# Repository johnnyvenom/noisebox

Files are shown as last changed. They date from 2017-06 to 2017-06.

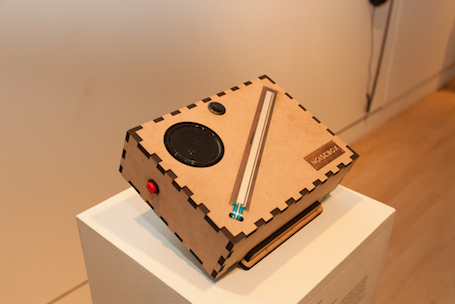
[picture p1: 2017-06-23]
Noisebox-2015-resources/images/noisebox1.jpg

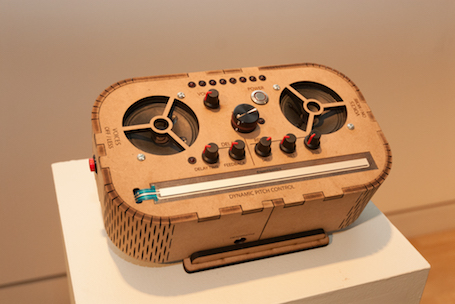
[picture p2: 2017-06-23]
Noisebox-2015-resources/images/noisebox2.jpg

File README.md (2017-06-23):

Noisebox rev3 - Fall 2016
=========================

## Setting up RPi: 

- Flashing new disk images: 
    - https://learn.adafruit.com/beaglebone-black-installing-operating-systems/
    - https://ccrma.stanford.edu/wiki/How_To_Get_Satellite_CCRMA
    - Won't flash holding down User Boot button? Use this: http://stackoverflow.com/questions/31725206/unable-to-flash-emmc-from-sd-card-beaglebone-black
- Check current OS: http://www.cyberciti.biz/faq/find-linux-distribution-name-version-number/
    - `cat /etc/*-release`
    - `lsb_release -a`
    - `uname -a`
    - `cat /proc/version
- Remote desktop for BBB: 
    - start vncserver `vncserver -geometry 1680x1050 -depth 24`
    - Mac: open screen share and put in IP address:5901
        + PW: tightvnc
    - info:
        + https://www.digitalocean.com/community/tutorials/how-to-set-up-vnc-server-on-debian-8
        + https://www.huement.com/web/beaglebone-screen-sharing-on-osx/
    - Advertise over Bonjour (not yet working): https://teachprimarycomputing.wordpress.com/2015/02/28/a-mac-geeks-guide-to-vnc-on-the-pi/
        + Netatalk for making shared device show up - check Ivan's distro. 
- Static IPs for multiple wireless networks (new procedure on Debian Jessie)
    + https://www.raspberrypi.org/forums/viewtopic.php?f=91&t=132553
- Power switch:
    + http://www.raspberry-pi-geek.com/Archive/2013/01/Adding-an-On-Off-switch-to-your-Raspberry-Pi
    + http://www.instructables.com/id/Simple-Raspberry-Pi-Shutdown-Button/
    + Long press shut down button: https://www.raspberrypi.org/forums/viewtopic.php?f=32&t=133111
    + 

## Ingredients list for a Satellite CCRMA (or similar) Noisebox: 

- Raspberry Pi ($52) rs - http://www.robotshop.com/ca/en/raspberry-pi-3-computer-board.html
- Arduino Nano ($13) rs - http://www.robotshop.com/ca/en/pro-mini-arduino-microcontroller.html
    + teensy
- Battery ($20) - ada - https://www.adafruit.com/products/1959
    + 2.4A
- Power Supply switch ($30) rs - http://www.robotshop.com/ca/en/on-off-power-supply-switch-raspberry-pi.html
- 3 x USB cable ($9)
- microSD card ($10)
- Buttons and switches ($5)
- Sensor: Linear FSR ($10?)
- IMU ($20)
- Speaker ($4)
- Amplifier ($5)
- USB audio I/O ($5)
- Breadboard ($5)
- Housing ($10)
- Hardware and jacks ($10)
- TOTAL: $208

### Static IP setup

Write down the following information. . .

- inet addr – 192.168.1.114 (Pi's Current IP Address)
- Bcast –  192.168.1.255 (The Broadcast IP Range)
- Mask –  255.255.255.0 (Subnet Mask Address)
- Gateway - 192.168.1.1
- Destination - 192.168.1.0

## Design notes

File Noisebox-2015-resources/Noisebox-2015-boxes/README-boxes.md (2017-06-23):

Noisebox Enclosures
===================

25 July - Saturday:

Revisions to make:
1. Reduce overall dimensions to 11 x 2.5 x 6.5. Yes? 
2. Reduce walls by 1mm on each flat side to fit better. 
3. Etch out recesses for potentiometers to set in. 
4. Remove pot guide holes - drill separately after. 
5. Add text - Pitch control; voices; 
6. Add arrows to voices LEDS
7. LEDS for voices and delay indicator
8. Recess for headphone

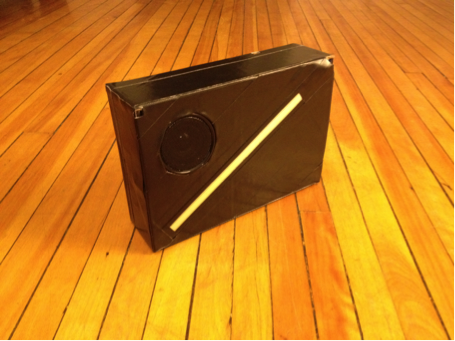
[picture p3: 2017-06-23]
Noisebox-2015-resources/images/noisebox0.png

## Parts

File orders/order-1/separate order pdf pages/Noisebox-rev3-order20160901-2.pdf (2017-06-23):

Noisebox rev3 materials list
2016-08-01 John Sullivan - IDMIL
Item # | Description | Vendor Item ID Cost/Unit Quant Cost/Instr. | Notes | Use
Processing 1 2 3 4 5 6 | Raspberry Pi 3 Teensy 3.2 Battery 5V 2.4A Sensor I/O cape WiFi dongle microSD card 8gb | RobotShop RB-Ras-12 CAD 51.99 1 CAD 51.99 RobotShop RB-Pjr-04 CAD 25.38 1 CAD 25.38 Abra BAT-PB-01 CAD 39.94 1 CAD 39.94 in house Ivan 1 Abra PI-WIFI-M CAD 10.57 1 Abra BBB-8GB-10 CAD 13.93 1 CAD 13.93 | Have at least 4 at IDMIL… enough to start | Core processor Sensor processing and filtering Wireless power supply Sensor I/O Wireless communication RPi storage

Sensors and controls

Sound output

Hardware, cables, accessories

7 | Buttons - mom (power) | Abra | PBS-33MM-BLCAD 2.09 | 1 | CAD 2.09 | RPi soft shutdown
8 | LED - Power (Blue) | Abra | LED-5B | CAD 1.11 | 1 | CAD 1.11 | | Power indicator (optional)
9 | Switch - Power | Abra | COM-11155 CAD 2.10 | 1 | CAD 2.10 | Power supply switch (after soft shutdown)
10 | Buttons (voice on - grn) | RobotShop RB-Spa-674 CAD 2.50 | 1 | CAD 2.50 | Voice(s) on
11 | Buttons (voice off - red) | RobotShop RB-Spa-324 CAD 2.50 | 1 | CAD 2.50 | Voice(s) off
12 | Linear SoftPot - 200mm | Digikey | 905-1051-ND CAD 16.66 | 1 | CAD 16.66 | Dynamic pitch control
13 | Analog accelerometer | RobotShop RB-Ite-11 | CAD 3.77 | 1 | CAD 3.77 | Motion acquisition
14 | Knob (volume) | Digikey | PDB182-E420K-103A-ND CAD 2.70 | 1 | 50K 2 gang (not in stock). Check part #. | Volume knob
15 | USB sound card | Abra | 1475-ADA | CAD 6.93 | 1 | CAD 6.93 | | Audio I/O
| OPTION 1
16 | Stereo Class-D amp | RobotShop RB-Dfr-419 CAD 7.56 | 1 | CAD 7.56 | Audio amplifier
17 | Speaker 4Ω 3W | Abra | 1314-ADA | CAD 2.73 | 2 | CAD 5.46 | | Audio output
18 | 3.5mm TRS male | Abra | 867-ADA | CAD 4.13 | 1 | CAD 4.13 | | Audio cable - sound card to amp
| OPTION 2
19 | USB powered speakers | Abra | 1363-ADA | CAD 13.93 | 1 | | | Alternative to Option 1 but not as good
20 | Acrylic housing | in house | Ivan | | 1 | | | Instrument body
21 | USB cable panel mount | Abra | 937-ADA | CAD 5.53 | 1 | CAD 5.53 | | Panel mount battery charging port
22 | Ethernet cable panel mount | Abra | 909-ADA | CAD 6.85 | 1 | CAD 6.85 | | Panel mount ethernet port
23 | Protoboard (3pk) | Abra | 571-ADA | CAD 5.83 | 1 | CAD 5.83 | misc bulk hardware; 3pack for 17.95 | Wiring hub
24 | headers male 1x40 (10pk) | RobotShop RB-Cyt-53 | CAD 0.23 | 3 | CAD 0.69 | misc bulk hardware; 10 pack = $2.31 | Wiring connections
25 | headers female 1x40 (1pk) | RobotShop RB-Cyt-58 | CAD 0.44 | 1 | CAD 0.44 | misc bulk hardware | Wiring connections - Teensy
26 | headers female 2x20 (1pk) | Abra | 1037-POLOLUCAD 1.75 | 1 | CAD 1.75 | misc bulk hardware | RPi to cape connector
27 | Button quick connect wires (5pk) | Abra | 1152-ADA | CAD 1.39 | 1 | | misc bulk hardware; 5 pack = $6.93 | Button wiring connectors
28 | JST connectors | Abra | PRT-09749 CAD 1.53 | 4 | misc bulk hardware | Button wire to protoboard
29 | 2.5mm standoffs (4pack set) | Abra | 1952P | CAD 1.95 | 1 | | misc bulk hardware | Mounting hardware
30 | M2.5 spacers (25pk) | Abra | 1975P | CAD 0.08 | 4 | CAD 0.33 | misc bulk hardware; 25 pack = $2.09 | Mounting hardware
31 | M2.5 Machine hex nut (25pk) | Abra | 1967P | CAD 0.06 | 4 | CAD 0.22 | misc bulk hardware; 25 pack = $1.39 | Mounting hardware
32 | M2.5 Machine screw (25pk) | Abra | 1968P | CAD 0.06 | 4 | CAD 0.22 | misc bulk hardware; 25 pack = $1.39 | Mounting hardware
33 | LED holder | Abra | LMH-1 | CAD 0.15 | 1 | | misc bulk hardware | Mounting hardware
TOTAL INSTRUMENT COST: CAD 207.93

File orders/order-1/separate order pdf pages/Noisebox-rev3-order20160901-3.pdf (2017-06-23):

Noisebox rev3 materials list | Vendor comparison
John Sullivan | Color key: 1st choice
USD 1.00 = CAD 1.31 | 1st choice
# | Description

Quantity
per inst. | DigiKey | Cost per unit

Cost per
instrument RobotShop

Cost per
unit

Cost per
instrument Abra

Cost per
unit

Cost per
instrument | Adafruit | Cost (USD) | Cost (CAD) | Other | Item | Cost

Quantity in
lab | Notes | Use
Processing
1 | Raspberry Pi 3 | 1 | 1690-1000-ND CAD | 67.54 | RB-Ras-12 | CAD 51.99 CAD 51.99 | RASPBERRY PI 3CAD 62.71 | 3055 | USD 39.95 | CAD 52.32 | 0 | Core processor
2 | Teensy 3.2 | 1 | 1568-1231-ND CAD | 31.99 | RB-Pjr-04 | CAD 25.38 CAD 25.38 | TEENSY-3.2 CAD 29.33 | 2756 | USD 19.95 | CAD 26.13 | 2 | Adafruit out of stock | Sensor processing and filtering
3 | Battery 5V 2.4A | 1 | n/a | n/a | BAT-PB-01 CAD 39.94 CAD 39.94 | n/a | Amazon.ca RAVPower 6700mAh CAD 20.79 | 4 | Have at least 4 at IDMIL… enough to start | Wireless power supply
4 | Sensor I/O cape | 1 | n/a | n/a | n/a | n/a | Pi Muxi Control Ivan | Ivan | Sensor I/O
5 | WiFi dongle | 1 | 1528-1439-ND CAD | 16.99 | RB-Ada-67 CAD 15.32 | PI-WIFI-M | CAD 10.57 CAD 10.57 | 814 | USD 11.95 | CAD 15.65 | 4 | Wireless communication
6 | microSD card 8gb | 1 | P17033-ND | CAD | 14.72 | BBB-8GB-10 CAD 13.93 CAD 13.93 | 1294 | USD 9.95 | CAD 13.03 | 1 | RPi storage
Sensors and controls
7 | Buttons - mom (power) | 1 | EG1900-ND | CAD | 2.73 | PBS-33MM-BLCAD 2.09 CAD | 2.09 | 0 | DigiKey unit cost: 2.73 | RPi soft shutdown
8 | LED - Power (Blue) | 1 | LED-5B | CAD 1.11 CAD | 1.11 | Power indicator (optional)
9 | Switch - Power | 1 | COM-11155 CAD 2.10 CAD | 2.10 | 481 | USD 4.95 | CAD 6.48 | Power supply switch (after soft shutdown)
10 | Buttons (voice on - grn) | 1 | EG1930-ND | CAD | 5.46 | RB-Spa-674 CAD 2.50 CAD | 2.50 | COM-90341 CAD 2.73 | 1504 | USD 0.95 | CAD 1.24 | 0 | Also black and yellow from Adafruit | Voice(s) on
11 | Buttons (voice off - red) | 1 | EG1930-ND | CAD | 5.46 | RB-Spa-324 CAD 2.50 CAD | 2.50 | COM-09336 CAD 2.73 | 1445 | USD 0.95 | CAD 1.24 | 0 | Voice(s) off
12 | Linear SoftPot - 200mm | 1 | 905-1051-ND CAD | 16.66 CAD 16.66 | SEN-08679 CAD 30.73 | 0 | Dynamic pitch control
13 | Analog accelerometer | 1 | 1568-1044-ND CAD | 21.13 | RB-Ite-11 | CAD 3.77 CAD | 3.77 | SENS-33 | CAD 11.19 | 163 | USD 14.95 | CAD 19.58 | 0 | Motion acquisition
14 | Knob (volume) | 1 | PDB182-E420K-103A-ND CAD | 2.70 CAD 2.70 | 4 | 50K double stack / not currently in stock… check part #. | Volume knob
Sound output
15 | USB sound card | 1 | 1475-ADA | CAD 6.93 CAD | 6.93 | 1475 | USD 4.95 | CAD 6.48 | 4 | Audio I/O
OPTION 1
16 | Stereo Class-D amp | 1 | 1528-1380-ND CAD | 12.65 | RB-Dfr-419 CAD 7.56 CAD | 7.56 | 1552-ADA | CAD 13.93 | 987 | USD 8.95 | CAD 11.72 | 2 | Ref: https://goo.gl/4Ec353 | Audio amplifier
17 | Speaker 4Ω 3W | 2 | n/a | 1314-ADA | CAD 2.73 CAD | 5.46 | 1314 | USD 3.90 | CAD 5.11 | Addison | 3 | Unit cost: USD 1.95 | Audio output
18 | 3.5mm TRS male | 1 | 867-ADA | CAD 4.13 CAD | 4.13 | 876 | USD 2.95 | CAD 3.86 | Addison | 0 | Audio cable - sound card to amp
OPTION 2
19 | USB powered speakers | 1 | 1363-ADA | CAD 13.93 | 1363 | USD 9.95 | CAD 13.03 | 0 | Sound output
Hardware, cables, accessories
20 | Acrylic housing | 1 | Ivan | Ivan | Instrument body
21 | USB cable panel mount | 1 | SC1837-ND | CAD | 17.61 | 937-ADA | CAD 5.53 CAD | 5.53 | 937 | USD 3.95 | CAD 5.17 | 0 | Panel mount battery charging port
22 | Ethernet cable panel mount | 1 | EHRJ45P6S-ND CAD | 14.67 | 909-ADA | CAD 6.85 CAD | 6.85 | 909 | USD 4.95 | CAD 6.48 | 0 | Panel mount ethernet port
23 | Protoboard (3pk) | 1 | 571-ADA | CAD 5.83 CAD | 5.83 | 571 | USD 12.50 | CAD 16.37 | 2/0 | *3 pack from Abra 17.50 | Wiring hub
24 | headers male 1x40 (10pk) | 3 | RB-Cyt-53 | CAD 2.31 CAD | 0.69 | SH-2 | CAD 2.91 | 0 | RS = 10 pack; Abra unit price = .97 | Wiring connections
25 | headers female 1x40 (1pk) | 1 | RB-Cyt-58 | CAD 0.44 CAD | 0.44 | FH-1 | CAD 0.97 | 0 | 1-pack: order multiples | Wiring connections - Teensy
26 | headers female 2x20 (1pk) | 1 | RB-Ada-27 CAD 3.78 | 1037-POLOLUCAD 1.75 CAD | 1.75 | 0 | RobotShop = 5 pack; Abra = 2x20 block | RPi to cape connector
27 | Button quick connect wires (5pk) | 1 | 1152-Ada | CAD 6.93 CAD | 6.93 | 1152 | USD 4.95 | CAD 6.48 | Button wiring connectors
28 | JST connectors | 4 | 455-2247-ND CAD 2.9 | PRT-09749 CAD 1.53 CAD | 6.12 | Unit price (Abra): $1.53 | Button wire to protoboard
29 | 2.5mm standoffs (4pack set) | 1 | 1952P | CAD 1.95 CAD | 1.95 | 2336 | USD 1.50 | CAD 1.96 | optional | ***MUST BE 2.5M not 3M | Mounting hardware
30 | M2.5 spacers (25pk) | 4 | 1975P | CAD 2.09 | multipack | Mounting hardware
31 | M2.5 Machine hex nut (25pk) | 4 | 1967P | CAD 1.39 | multipack | Mounting hardware
32 | M2.5 Machine screw (25pk) | 4 | 1968P | CAD 1.39 | multipack | Mounting hardware
33 | LED holder | 1 | LMH-1 | CAD 0.15 CAD | 0.15 | multipack | Mounting hardware
* Should get M2.5 screws 20mm

2016-08-01

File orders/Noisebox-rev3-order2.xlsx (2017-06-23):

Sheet: Order Form
FOAPAL: |  | PROJECT: John Sullivan - Noisebox rev3 (comprehensive exams)
Quantity | Description | Part number/Supplier ID | URL | Price | (All prices are CAD) |  | Ordered Date
ABRA ELECTRONICS
1 | Pololu Female crimp pins | 1930-POLOLU | https://abra-electronics.com/connectors/connector-housing/1930-pololu-female-crimp-pins-for-01-housings-100-pack-1930-pololu.html | $8.33 |  | $8.33
1 | Polulu male crimp pins | 1931-POLOLU | https://abra-electronics.com/connectors/connector-housing/1931-pololu-male-crimp-pins-for-01-housings-100-pack-1931-pololu.html | $11.13 |  | $11.13
8 | Buttons - 33m | PBS-33MM-BL | https://abra-electronics.com/electromechanical/switches/pushbutton-switches/pbs-33mm-bl-push-button-33mm-blue-pbs-33mm-bl.html | $2.09 |  | $8.34
1 | F/F 6" jumper wires | 266-ADA | https://abra-electronics.com/wirecable/jumper-wire-assembly/266-premium-female-female-jumper-wires-40-x-6-266-ada.html | $8.33 |  | $8.33
1 | F/F 3" jumper wires | 794-ADA | https://abra-electronics.com/wirecable/jumper-wire-assembly/794-premium-female-female-jumper-wires-40-x-3-75mm-794-ada.html | $8.33 |  | $8.33
1 | M/M 3" jumper wires | 759-ADA | https://abra-electronics.com/robotics-embedded-electronics/cables-wires/759-premium-male-male-jumper-wires-40-x-3-75mm-759-ada.html | $8.33 |  | $8.33
1 | F/M 3" jumper wires | 825-ADA | https://abra-electronics.com/robotics-embedded-electronics/cables-wires/825-premium-female-male-extension-jumper-wires-40-x-3-75mm-825-ada.html | $8.33 |  | $8.33
1 | F/M 6" jumper wires | 826-ADA | https://abra-electronics.com/robotics-embedded-electronics/cables-wires/826-premium-female-male-extension-jumper-wires-40-x-6-150mm-826-ada.html | $8.33 |  | $8.33
1 | M/M 6" jumper wires | 758-ADA | https://abra-electronics.com/robotics-embedded-electronics/cables-wires/758-premium-male-male-jumper-wires-40-x-6-150mm-758-ada.html | $8.33 |  | $8.33
2 | Perf board w solder pads | BRD-ARD-1 | https://abra-electronics.com/boards/printed-circuit-boards/brd-ard-1-pcb-81cm-x-63cm-brd-ard-1.html | $4.89 |  | $9.77
1 | Perf board bare | 22-518 | https://abra-electronics.com/boards/prepunched-boards/22-518-3-3-4-x-8-perforated-bare-phenolic-prototype-board.html | $9.94 |  | $9.94
4 | Button - power/momentary | 3105-ADA | https://abra-electronics.com/electromechanical/switches/pushbutton-switches/3105-ada-mini-illuminated-momentary-pushbutton-blue-power-symbol.html | $2.73 |  | $10.92
2 | Button - 16mm - grn | PBS-A-110 | https://abra-electronics.com/switches/pushbutton-switches/pbs-a-110-16mm-panel-mount-momentary-pushbutton-green-pbs-a-110.html | $1.81 |  | $3.61
2 | Button - 16mm - black | PBS-A-105 | https://abra-electronics.com/switches/pushbutton-switches/pbs-a-105-16mm-panel-mount-momentary-pushbutton-black-pbs-a-105.html | $1.67 |  | $3.33
2 | Button - 16mm - red | PBS-A-100 | https://abra-electronics.com/switches/pushbutton-switches/pbs-a-100-16mm-panel-mount-momentary-pushbutton-red-pbs-a-100.html | $1.67 |  | $3.33
4 | USB power supply cable w/ switch | PI2-SWITCH | https://abra-electronics.com/robotics-embedded-electronics/raspberry-pi-en-3/cables-connectors/pi2-switch-micro-usb-cable-w-switch.html | $7.49 |  | $29.96
 |  |  |  |  | SUBTOTAL | $135.70
 |  |  |  |  | Shipping | $13.99
 |  |  |  |  | Taxes | $22.43
 |  |  |  |  | Total: | $172.12
Order details and totals
 |  |  |  |  | Total for order: | $172.12

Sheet: Instrument - parts list
Noisebox rev3 materials list
2016-08-01 | John Sullivan - IDMIL
Item # | Description | Vendor | Item ID | Cost/Unit | Quant | Cost/Instr. | Notes | Use
Processing
1 | Raspberry Pi 3 | RobotShop | RB-Ras-12 (http://www.robotshop.com/ca/en/raspberry-pi-3-computer-board.html) | CAD 51.99 | 1 | CAD 51.99 |  | Core processor
2 | Teensy 3.2 | RobotShop | RB-Pjr-04 (http://www.robotshop.com/ca/en/teensy-32-usb-microcontroller-development-board.html) | CAD 25.38 | 1 | CAD 25.38 |  | Sensor processing and filtering
3 | Battery 5V 2.4A | Abra | BAT-PB-01 (https://abra-electronics.com/batteries-holders/battery-packs-rechargeable/bat-pb-01-8000-mah-rapid-charge-power-bank-with-14-integrated-leds-for-iphone-samsun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) | CAD 39.94 | 1 | CAD 39.94 | Have at least 4 at IDMIL… enough to start | Wireless power supply
4 | Sensor I/O cape | in house | Ivan |  | 1 |  |  | Sensor I/O
5 | WiFi dongle | Abra | PI-WIFI-M (https://abra-electronics.com/robotics-embedded-electronics/beagle-bone/pi-wifi-m-usb-wireless-miniature-module-pi-wifi-m.html) | CAD 10.57 | 1 |  |  | Wireless communication
6 | microSD card 8gb | Abra | BBB-8GB-10 (https://abra-electronics.com/robotics-embedded-electronics/beagle-bone/bbb-8gb-4-micro-sdhc-memory-card-8gb-class-4-bbb-8gb-4.html) | CAD 13.93 | 1 | CAD 13.93 |  | RPi storage
Sensors and controls
7 | Buttons - mom (power) | Abra | PBS-33MM-BL (https://abra-electronics.com/robotics-embedded-electronics/sparkfun/components/buttons-switches/pbs-33mm-bl-push-button-33mm-blue-pbs-33mm-bl.html) | CAD 2.09 | 1 | CAD 2.09 |  | RPi soft shutdown
8 | LED - Power (Blue) | Abra | LED-5B (https://abra-electronics.com/opto-illumination/leds-bare/5mmt13-4-leds/led-5b-5mm-blue-led-led-5b.html) | CAD 1.11 | 1 | CAD 1.11 |  | Power indicator (optional)
9 | Switch - Power | Abra | COM-11155 (https://abra-electronics.com/robotics-embedded-electronics/sparkfun/components/buttons-switches/com-11155-rocker-switch-round-w-blue-led-com-11155.html) | CAD 2.10 | 1 | CAD 2.10 |  | Power supply switch (after soft shutdown)
10 | Buttons (voice on - grn) | RobotShop | RB-Spa-674 (http://www.robotshop.com/ca/en/concave-button-red.html) | CAD 2.50 | 1 | CAD 2.50 |  | Voice(s) on
11 | Buttons (voice off - red) | RobotShop | RB-Spa-324 (http://www.robotshop.com/ca/en/sfe-concave-button-green.html) | CAD 2.50 | 1 | CAD 2.50 |  | Voice(s) off
12 | Linear SoftPot - 200mm | Digikey | 905-1051-ND (http://www.digikey.ca/product-search/en?keywords=905-1051-ND) | CAD 16.66 | 1 | CAD 16.66 |  | Dynamic pitch control
13 | Analog accelerometer | RobotShop | RB-Ite-11 (http://www.robotshop.com/ca/en/3-axis-accelerometer-module.html) | CAD 3.77 | 1 | CAD 3.77 |  | Motion acquisition
14 | Knob (volume) | Digikey | PDB182-E420K-103A-ND (https://www.digikey.ca/product-detail/en/bourns-inc/PDB182-E420K-103A/PDB182-E420K-103A-ND/3780709) | CAD 2.70 | 1 |  | 50K 2 gang (not in stock). Check part #. | Volume knob
Sound output
15 | USB sound card | Abra | 1475-ADA (https://abra-electronics.com/computer-accessories/usb-adapters-cables-hubs-other/1475-ada-usb-audio-adapter-works-with-raspberry-pi-1475-ada.html) | CAD 6.93 | 1 | CAD 6.93 |  | Audio I/O
 | OPTION 1
16 | Stereo Class-D amp | RobotShop | RB-Dfr-419 (http://www.robotshop.com/ca/en/3w-audio-stereo-amplifier.html) | CAD 7.56 | 1 | CAD 7.56 |  | Audio amplifier
17 | Speaker 4Ω 3W | Abra | 1314-ADA (https://abra-electronics.com/audible-devices/speakers/1314-ada-speaker-3-diameter-4-ohm-3-watt-1314-ada.html) | CAD 2.73 | 2 | CAD 5.46 |  | Audio output
18 | 3.5mm TRS male | Abra | 867-ADA (https://abra-electronics.com/robotics-embedded-electronics/adafruit/wires-cables/876-ada-stereo-35mm-plug-plug-audio-cable-6-feet-876-ada.html) | CAD 4.13 | 1 | CAD 4.13 |  | Audio cable - sound card to amp
 | OPTION 2
19 | USB powered speakers | Abra | 1363-ADA (https://abra-electronics.com/audible-devices/speakers/1363-ada-usb-powered-speakers-1363-ada.html) | CAD 13.93 | 1 |  |  | Alternative to Option 1 but not as good
Hardware, cables, accessories
20 | Acrylic housing | in house | Ivan |  | 1 |  |  | Instrument body
21 | USB cable panel mount | Abra | 937-ADA (https://abra-electronics.com/robotics-embedded-electronics/adafruit/raspberry-pi-en-2/cables/937-panel-mount-usb-cable-b-female-to-micro-b-male-937-ada.html) | CAD 5.53 | 1 | CAD 5.53 |  | Panel mount battery charging port
22 | Ethernet cable panel mount | Abra | 909-ADA (https://abra-electronics.com/robotics-embedded-electronics/adafruit/raspberry-pi-en-2/cables/909-panel-mount-ethernet-extension-cable-909-ada.html) | CAD 6.85 | 1 | CAD 6.85 |  | Panel mount ethernet port
23 | Protoboard (3pk) | Abra | 571-ADA (https://abra-electronics.com/boards/printed-circuit-boards/571-ada-adafruit-perma-proto-half-sized-breadboard-pcb-3-pack.html) | CAD 5.83 | 1 | CAD 5.83 | misc bulk hardware; 3pack for 17.95 | Wiring hub
24 | headers male 1x40 (10pk) | RobotShop | RB-Cyt-53 (http://www.robotshop.com/ca/en/break-away-headers-straight.html) | CAD 0.23 | 3 | CAD 0.69 | misc bulk hardware; 10 pack = $2.31 | Wiring connections
25 | headers female 1x40 (1pk) | RobotShop | RB-Cyt-58 (http://www.robotshop.com/ca/en/straight-female-headers.html) | CAD 0.44 | 1 | CAD 0.44 | misc bulk hardware | Wiring connections - Teensy
26 | headers female 2x20 (1pk) | Abra | 1037-POLOLU (https://abra-electronics.com/connectors/headers/female/1037-pololu-0.100-2.54-mm-female-header-2x20-pin-straight.html) | CAD 1.75 | 1 | CAD 1.75 | misc bulk hardware | RPi to cape connector
27 | Button quick connect wires (5pk) | Abra | 1152-ADA (https://abra-electronics.com/robotics-embedded-electronics/adafruit/components-parts/buttons/1152-ada-arcade-button-quick-connect-wire-pair-set-of-10-pairs-11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) | CAD 1.39 | 1 |  | misc bulk hardware; 5 pack = $6.93 | Button wiring connectors
28 | JST connectors | Abra | PRT-09749 (https://abra-electronics.com/connectors/jst-connectors/prt-09749-jst-right-angle-connector-through-hole-2-pin-prt-09749.html) | CAD 1.53 | 4 |  | misc bulk hardware | Button wire to protoboard
29 | 2.5mm standoffs (4pack set) | Abra | 1952P (https://abra-electronics.com/hardware/standoffs/standoffs-aluminum-m-f/1952p-aluminum-standoff-for-raspberry-pi-11mm-length-m2.5-thread-m-f-4-pack.html) | CAD 1.95 | 1 |  | misc bulk hardware | Mounting hardware
30 | M2.5 spacers (25pk) | Abra | 1975P (https://abra-electronics.com/hardware/spacers/1975p-nylon-spacer-12mm-length-4mm-od-2.7mm-id-25-pack.html) | CAD 0.08 | 4 | CAD 0.33 | misc bulk hardware; 25 pack = $2.09 | Mounting hardware
31 | M2.5 Machine hex nut (25pk) | Abra | 1967P (https://abra-electronics.com/hardware/metric-hardware-nickel-plated-nuts/1967p-machine-hex-nut-m2.5-25-pack.html) | CAD 0.06 | 4 | CAD 0.22 | misc bulk hardware; 25 pack = $1.39 | Mounting hardware
32 | M2.5 Machine screw (25pk) | Abra | 1968P (https://abra-electronics.com/hardware/metric-hardware-round-phillips-head-screws/1968p-machine-screw-m2.5-6mm-length-phillips-25-pack.html) | CAD 0.06 | 4 | CAD 0.22 | misc bulk hardware; 25 pack = $1.39 | Mounting hardware
33 | LED holder | Abra | LMH-1 (https://abra-electronics.com/opto-illumination/led-mounting-hardware/lmh-1-led-holder-5mm-lmh-1.html) | CAD 0.15 | 1 |  | misc bulk hardware | Mounting hardware
 |  |  |  |  | TOTAL INSTRUMENT COST: | CAD 207.93

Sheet: Parts list - Vendor comparison
Noisebox rev3 materials list |  | Vendor comparison
2016-08-01 |  | John Sullivan |  |  | Color key: | 1st choice
 |  |  |  |  |  |  |  |  |  |  |  |  | USD 1.00 = | CAD 1.31 |  | 1st choice
# | Description | Quantity per inst. | DigiKey | Cost per unit | Cost per instrument | RobotShop | Cost per unit | Cost per instrument | Abra | Cost per unit | Cost per instrument | Adafruit | Cost (USD) | Cost (CAD) | Other | Item | Cost | Quantity in lab | Notes | Use
Processing
1 | Raspberry Pi 3 | 1 | 1690-1000-ND (http://www.digikey.ca/scripts/DkSearch/dksus.dll?Detail&itemSeq=205554137&uq=636082410230958991) | CAD 67.54 |  | RB-Ras-12 (http://www.robotshop.com/ca/en/raspberry-pi-3-computer-board.html) | CAD 51.99 | CAD 51.99 | RASPBERRY PI 3 (https://abra-electronics.com/robotics-embedded-electronics/raspberry-pi-en-3/boards-shields/raspberry-pi-3-project-board.html) | CAD 62.71 |  | 3055 (https://www.adafruit.com/products/3055) | USD 39.95 | CAD 52.32 |  |  |  | 0 |  | Core processor
2 | Teensy 3.2 | 1 | 1568-1231-ND (http://www.digikey.ca/product-detail/en/sparkfun-electronics/DEV-13736/1568-1231-ND/5721426) | CAD 31.99 |  | RB-Pjr-04 (http://www.robotshop.com/ca/en/teensy-32-usb-microcontroller-development-board.html) | CAD 25.38 | CAD 25.38 | TEENSY-3.2 (https://abra-electronics.com/robotics-embedded-electronics/teensy/teensy3.2-teensy-3.2-usb-development-board.html) | CAD 29.33 |  | 2756 (https://www.adafruit.com/products/2756) | USD 19.95 | CAD 26.13 |  |  |  | 2 | Adafruit out of stock | Sensor processing and filtering
3 | Battery 5V 2.4A | 1 | n/a |  |  | n/a |  |  | BAT-PB-01 (https://abra-electronics.com/batteries-holders/battery-packs-rechargeable/bat-pb-01-8000-mah-rapid-charge-power-bank-with-14-integrated-leds-for-iphone-samsun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) | CAD 39.94 | CAD 39.94 | n/a |  |  | Amazon.ca | RAVPower 6700mAh | CAD 20.79 (https://www.amazon.ca/External-Battery-RAVPower-Portable-Technology/dp/B00Y9KFIH2/) | 4 | Have at least 4 at IDMIL… enough to start | Wireless power supply
4 | Sensor I/O cape | 1 | n/a |  |  | n/a |  |  | n/a |  |  | n/a |  |  | Pi Muxi Control | Ivan |  | Ivan |  | Sensor I/O
5 | WiFi dongle | 1 | 1528-1439-ND (http://www.digikey.com/product-detail/en/adafruit-industries-llc/814/1528-1439-ND/5761207) | CAD 16.99 |  | RB-Ada-67 (http://www.robotshop.com/ca/en/mini-usb-wifi-module.html) | CAD 15.32 |  | PI-WIFI-M (https://abra-electronics.com/robotics-embedded-electronics/beagle-bone/pi-wifi-m-usb-wireless-miniature-module-pi-wifi-m.html) | CAD 10.57 | CAD 10.57 | 814 (https://www.adafruit.com/products/814) | USD 11.95 | CAD 15.65 |  |  |  | 4 |  | Wireless communication
6 | microSD card 8gb | 1 | P17033-ND (http://www.digikey.ca/product-detail/en/panasonic-electronic-components/RP-SMLF08DA1/P17033-ND/5119440) | CAD 14.72 |  |  |  |  | BBB-8GB-10 (https://abra-electronics.com/robotics-embedded-electronics/beagle-bone/bbb-8gb-4-micro-sdhc-memory-card-8gb-class-4-bbb-8gb-4.html) | CAD 13.93 | CAD 13.93 | 1294 (https://www.adafruit.com/products/1294) | USD 9.95 | CAD 13.03 |  |  |  | 1 |  | RPi storage
Sensors and controls
7 | Buttons - mom (power) | 1 | EG1900-ND (http://www.digikey.ca/product-detail/en/e-switch/RP3502ABLK/EG1900-ND/280446) | CAD 2.73 |  |  |  |  | PBS-33MM-BL (https://abra-electronics.com/robotics-embedded-electronics/sparkfun/components/buttons-switches/pbs-33mm-bl-push-button-33mm-blue-pbs-33mm-bl.html) | CAD 2.09 | CAD 2.09 |  |  |  |  |  |  | 0 | DigiKey unit cost: 2.73 | RPi soft shutdown
8 | LED - Power (Blue) | 1 |  |  |  |  |  |  | LED-5B (https://abra-electronics.com/opto-illumination/leds-bare/5mmt13-4-leds/led-5b-5mm-blue-led-led-5b.html) | CAD 1.11 | CAD 1.11 |  |  |  |  |  |  |  |  | Power indicator (optional)
9 | Switch - Power | 1 |  |  |  |  |  |  | COM-11155 (https://abra-electronics.com/robotics-embedded-electronics/sparkfun/components/buttons-switches/com-11155-rocker-switch-round-w-blue-led-com-11155.html) | CAD 2.10 | CAD 2.10 | 481 (https://www.adafruit.com/products/481) | USD 4.95 | CAD 6.48 |  |  |  |  |  | Power supply switch (after soft shutdown)
10 | Buttons (voice on - grn) | 1 | EG1930-ND (http://www.digikey.ca/product-detail/en/e-switch/RP3502ARED/EG1930-ND/280448) | CAD 5.46 |  | RB-Spa-674 (http://www.robotshop.com/ca/en/concave-button-red.html) | CAD 2.50 | CAD 2.50 | COM-90341 (https://abra-electronics.com/robotics-embedded-electronics/sparkfun/components/buttons-switches/com-09341-concave-button-green-com-09341.html) | CAD 2.73 |  | 1504 (https://www.adafruit.com/products/1504) | USD 0.95 | CAD 1.24 |  |  |  | 0 | Also black and yellow from Adafruit | Voice(s) on
11 | Buttons (voice off - red) | 1 | EG1930-ND (http://www.digikey.ca/product-detail/en/e-switch/RP3502ARED/EG1930-ND/280448) | CAD 5.46 |  | RB-Spa-324 (http://www.robotshop.com/ca/en/sfe-concave-button-green.html) | CAD 2.50 | CAD 2.50 | COM-09336 (https://abra-electronics.com/robotics-embedded-electronics/sparkfun/components/buttons-switches/com-09336-concave-button-red-com-09336.html) | CAD 2.73 |  | 1445 (https://www.adafruit.com/products/1445) | USD 0.95 | CAD 1.24 |  |  |  | 0 |  | Voice(s) off
12 | Linear SoftPot - 200mm | 1 | 905-1051-ND (http://www.digikey.ca/product-search/en?keywords=905-1051-ND) | CAD 16.66 | CAD 16.66 |  |  |  | SEN-08679 (https://abra-electronics.com/sensors/sensors-flex-force-en/sen-08679-softpot-membrane-potentiometer-200mm-sen-08679.html) | CAD 30.73 |  |  |  |  |  |  |  | 0 |  | Dynamic pitch control
13 | Analog accelerometer | 1 | 1568-1044-ND (http://www.digikey.ca/product-detail/en/sparkfun-electronics/SEN-09269/1568-1044-ND/5140809) | CAD 21.13 |  | RB-Ite-11 (http://www.robotshop.com/ca/en/3-axis-accelerometer-module.html) | CAD 3.77 | CAD 3.77 | SENS-33 | CAD 11.19 |  | 163 (https://www.adafruit.com/products/163) | USD 14.95 | CAD 19.58 |  |  |  | 0 |  | Motion acquisition
14 | Knob (volume) | 1 | PDB182-E420K-103A-ND (https://www.digikey.ca/product-detail/en/bourns-inc/PDB182-E420K-103A/PDB182-E420K-103A-ND/3780709) | CAD 2.70 | CAD 2.70 |  |  |  |  |  |  |  |  |  |  |  |  | 4 | 50K double stack / not currently in stock… check part #. | Volume knob
Sound output
15 | USB sound card | 1 |  |  |  |  |  |  | 1475-ADA (https://abra-electronics.com/computer-accessories/usb-adapters-cables-hubs-other/1475-ada-usb-audio-adapter-works-with-raspberry-pi-1475-ada.html) | CAD 6.93 | CAD 6.93 | 1475 (https://www.adafruit.com/products/1475) | USD 4.95 | CAD 6.48 |  |  |  | 4 |  | Audio I/O
 | OPTION 1
16 | Stereo Class-D amp | 1 | 1528-1380-ND (http://www.digikey.ca/product-detail/en/adafruit-industries-llc/987/1528-1380-ND/5629428) | CAD 12.65 |  | RB-Dfr-419 (http://www.robotshop.com/ca/en/3w-audio-stereo-amplifier.html) | CAD 7.56 | CAD 7.56 | 1552-ADA | CAD 13.93 |  | 987 (https://www.adafruit.com/products/987) | USD 8.95 | CAD 11.72 |  |  |  | 2 | Ref: https://goo.gl/4Ec353 | Audio amplifier
17 | Speaker 4Ω 3W | 2 | n/a |  |  |  |  |  | 1314-ADA (https://abra-electronics.com/audible-devices/speakers/1314-ada-speaker-3-diameter-4-ohm-3-watt-1314-ada.html) | CAD 2.73 | CAD 5.46 | 1314 (https://www.adafruit.com/products/1314) | USD 3.90 | CAD 5.11 | Addison |  |  | 3 | Unit cost: USD 1.95 | Audio output
18 | 3.5mm TRS male | 1 |  |  |  |  |  |  | 867-ADA (https://abra-electronics.com/robotics-embedded-electronics/adafruit/wires-cables/876-ada-stereo-35mm-plug-plug-audio-cable-6-feet-876-ada.html) | CAD 4.13 | CAD 4.13 | 876 (https://www.adafruit.com/products/876) | USD 2.95 | CAD 3.86 | Addison |  |  | 0 |  | Audio cable - sound card to amp
 | OPTION 2
19 | USB powered speakers | 1 |  |  |  |  |  |  | 1363-ADA (https://abra-electronics.com/audible-devices/speakers/1363-ada-usb-powered-speakers-1363-ada.html) | CAD 13.93 |  | 1363 (https://www.adafruit.com/products/1363) | USD 9.95 | CAD 13.03 |  |  |  | 0 |  | Sound output
Hardware, cables, accessories
20 | Acrylic housing | 1 |  |  |  |  |  |  |  |  |  |  |  |  | Ivan |  |  | Ivan |  | Instrument body
21 | USB cable panel mount | 1 | SC1837-ND (https://www.digikey.ca/product-detail/en/switchcraft-inc/EHUSBBABX/SC1837-ND/1832371) | CAD 17.61 |  |  |  |  | 937-ADA (https://abra-electronics.com/robotics-embedded-electronics/adafruit/raspberry-pi-en-2/cables/937-panel-mount-usb-cable-b-female-to-micro-b-male-937-ada.html) | CAD 5.53 | CAD 5.53 | 937 (https://www.adafruit.com/products/937) | USD 3.95 | CAD 5.17 |  |  |  | 0 |  | Panel mount battery charging port
22 | Ethernet cable panel mount | 1 | EHRJ45P6S-ND (http://www.digikey.ca/product-detail/en/switchcraft-inc/EHRJ45P6S/EHRJ45P6S-ND/2616381) | CAD 14.67 |  |  |  |  | 909-ADA (https://abra-electronics.com/robotics-embedded-electronics/adafruit/raspberry-pi-en-2/cables/909-panel-mount-ethernet-extension-cable-909-ada.html) | CAD 6.85 | CAD 6.85 | 909 (https://www.adafruit.com/products/909) | USD 4.95 | CAD 6.48 |  |  |  | 0 |  | Panel mount ethernet port
23 | Protoboard (3pk) | 1 |  |  |  |  |  |  | 571-ADA (https://abra-electronics.com/boards/printed-circuit-boards/571-ada-adafruit-perma-proto-half-sized-breadboard-pcb-3-pack.html) | CAD 5.83 | CAD 5.83 | 571 (https://www.adafruit.com/products/571) | USD 12.50 | CAD 16.37 |  |  |  | 2/0 | *3 pack from Abra 17.50 | Wiring hub
24 | headers male 1x40 (10pk) | 3 |  |  |  | RB-Cyt-53 (http://www.robotshop.com/ca/en/break-away-headers-straight.html) | CAD 2.31 | CAD 0.69 | SH-2 (https://abra-electronics.com/connectors/headers/male/sh-2-straight-male-snappable-header-1-row-x-40-pins-sh-2.html) | CAD 2.91 |  |  |  |  |  |  |  | 0 | RS = 10 pack; Abra unit price = .97 | Wiring connections
25 | headers female 1x40 (1pk) | 1 |  |  |  | RB-Cyt-58 (http://www.robotshop.com/ca/en/straight-female-headers.html) | CAD 0.44 | CAD 0.44 | FH-1 (https://abra-electronics.com/connectors/headers/female/fh-1-straight-female-header-receptacle-1-row-x-36-pins-fh-1.html) | CAD 0.97 |  |  |  |  |  |  |  | 0 | 1-pack: order multiples | Wiring connections - Teensy
26 | headers female 2x20 (1pk) | 1 |  |  |  | RB-Ada-27 (http://www.robotshop.com/ca/en/break-away-female-headers-20-pin-5pk.html) | CAD 3.78 |  | 1037-POLOLU (https://abra-electronics.com/connectors/headers/female/1037-pololu-0.100-2.54-mm-female-header-2x20-pin-straight.html) | CAD 1.75 | CAD 1.75 |  |  |  |  |  |  | 0 | RobotShop = 5 pack; Abra = 2x20 block | RPi to cape connector
27 | Button quick connect wires (5pk) | 1 |  |  |  |  |  |  | 1152-Ada (https://abra-electronics.com/robotics-embedded-electronics/adafruit/components-parts/buttons/1152-ada-arcade-button-quick-connect-wire-pair-set-of-10-pairs-11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) | CAD 6.93 | CAD 6.93 | 1152 (https://www.adafruit.com/products/1152) | USD 4.95 | CAD 6.48 |  |  |  |  |  | Button wiring connectors
28 | JST connectors | 4 | 455-2247-ND (http://www.digikey.ca/product-search/en?keywords=455-2247-ND) | CAD 2.9 |  |  |  |  | PRT-09749 (https://abra-electronics.com/connectors/jst-connectors/prt-09749-jst-right-angle-connector-through-hole-2-pin-prt-09749.html) | CAD 1.53 | CAD 6.12 |  |  |  |  |  |  |  | Unit price (Abra): $1.53 | Button wire to protoboard
29 | 2.5mm standoffs (4pack set) | 1 |  |  |  |  |  |  | 1952P (https://abra-electronics.com/hardware/standoffs/standoffs-aluminum-m-f/1952p-aluminum-standoff-for-raspberry-pi-11mm-length-m2.5-thread-m-f-4-pack.html) | CAD 1.95 | CAD 1.95 | 2336 (https://www.adafruit.com/products/2336) | USD 1.50 | CAD 1.96 | optional |  |  |  | ***MUST BE 2.5M not 3M | Mounting hardware
30 | M2.5 spacers (25pk) | 4 |  |  |  |  |  |  | 1975P (https://abra-electronics.com/hardware/spacers/1975p-nylon-spacer-12mm-length-4mm-od-2.7mm-id-25-pack.html) | CAD 2.09 |  |  |  |  |  |  |  |  | multipack | Mounting hardware
31 | M2.5 Machine hex nut (25pk) | 4 |  |  |  |  |  |  | 1967P (https://abra-electronics.com/hardware/metric-hardware-nickel-plated-nuts/1967p-machine-hex-nut-m2.5-25-pack.html) | CAD 1.39 |  |  |  |  |  |  |  |  | multipack | Mounting hardware
32 | M2.5 Machine screw (25pk) | 4 |  |  |  |  |  |  | 1968P (https://abra-electronics.com/hardware/metric-hardware-round-phillips-head-screws/1968p-machine-screw-m2.5-6mm-length-phillips-25-pack.html) | CAD 1.39 |  |  |  |  |  |  |  |  | multipack | Mounting hardware
33 | LED holder | 1 |  |  |  |  |  |  | LMH-1 (https://abra-electronics.com/opto-illumination/led-mounting-hardware/lmh-1-led-holder-5mm-lmh-1.html) | CAD 0.15 | CAD 0.15 |  |  |  |  |  |  |  | multipack | Mounting hardware
 | * Should get M2.5 screws 20mm

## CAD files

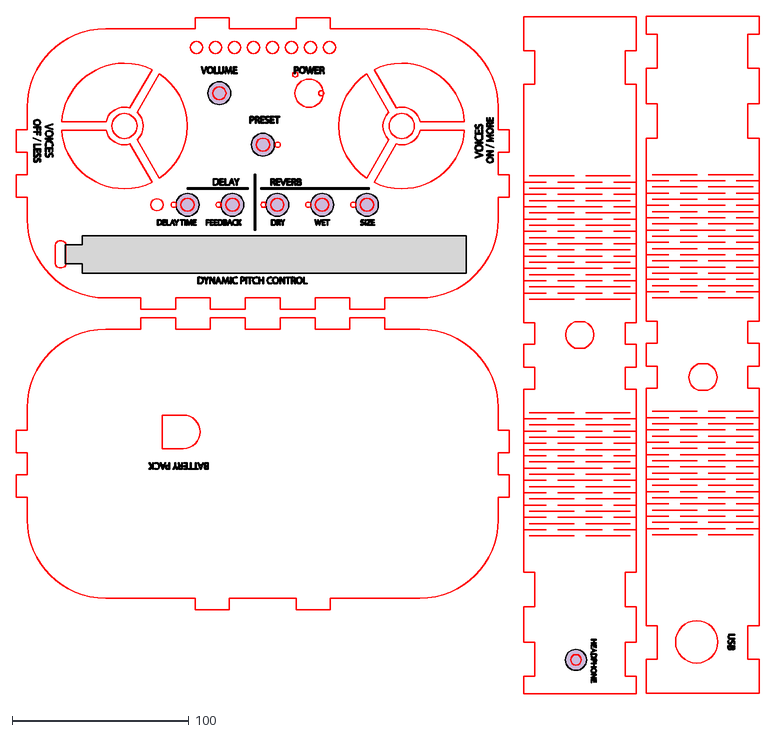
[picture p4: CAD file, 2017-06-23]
Noisebox-2015-resources/Noisebox-2015-boxes/noisebox-box6_cut-main.dxf
420.7 x 383.8

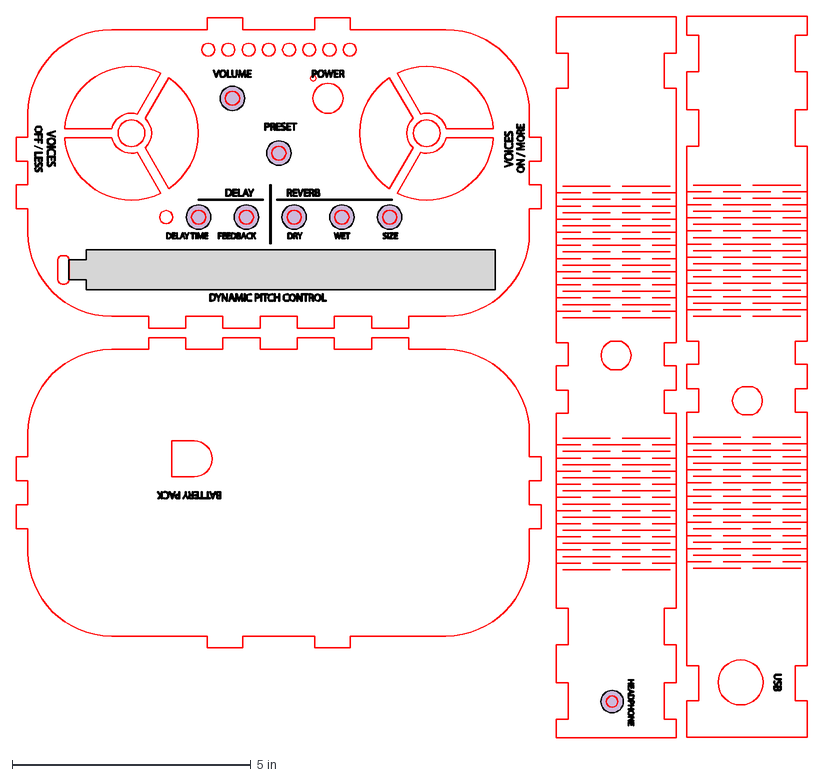
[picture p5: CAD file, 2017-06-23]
Noisebox-2015-resources/Noisebox-2015-boxes/cuts/noisebox-box6_cut-main.dxf
16.6 x 15.1 in

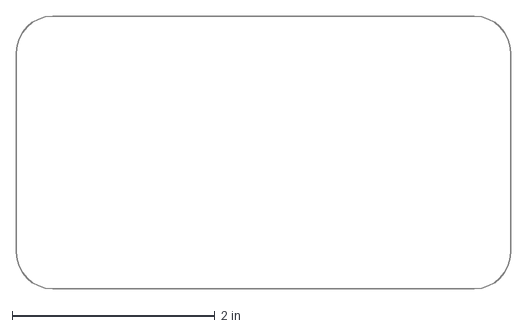
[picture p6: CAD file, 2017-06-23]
Noisebox-2015-resources/Noisebox-2015-boxes/cuts/rpi-platform.dxf
4.88 x 2.69 in

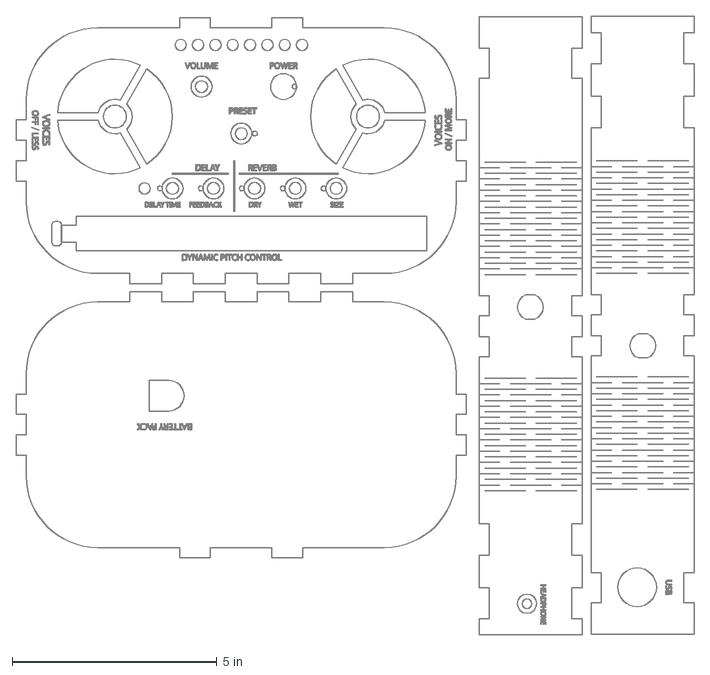
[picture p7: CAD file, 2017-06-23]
Noisebox-2015-resources/Noisebox-2015-boxes/lasercutter-files/noisebox-box7_cut.dxf
16.6 x 15.1 in

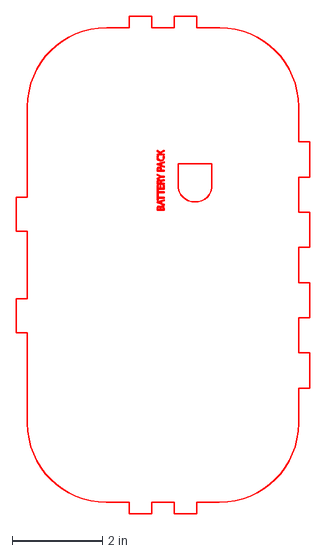
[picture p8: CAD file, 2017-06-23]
Noisebox-2015-resources/Noisebox-2015-boxes/noisebox-box6_bottom.dxf
6.50 x 11.0 in

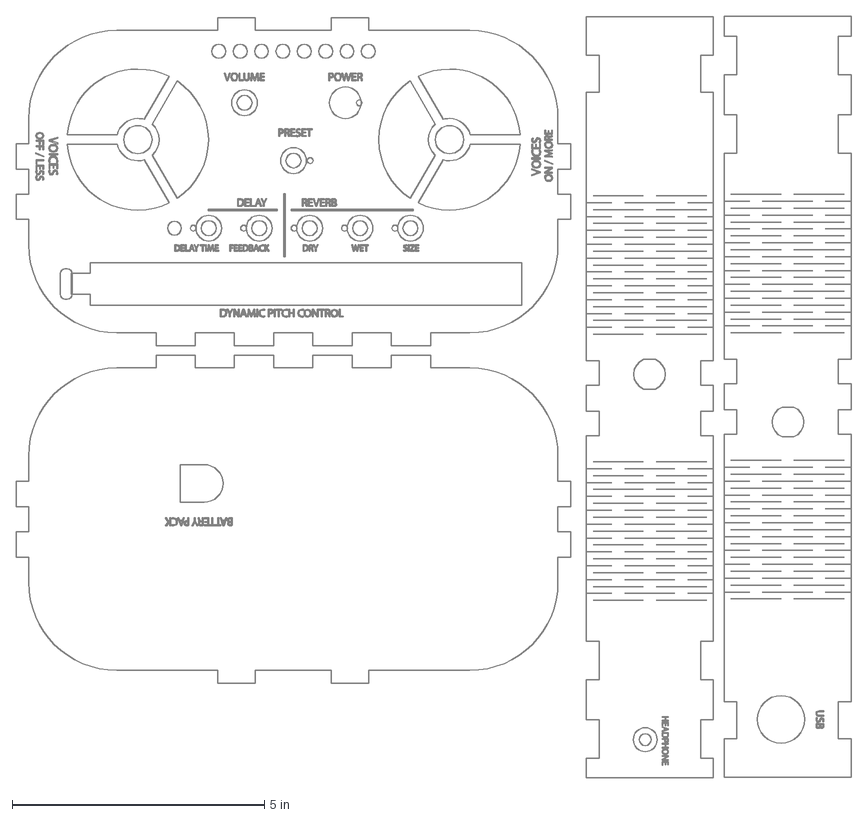
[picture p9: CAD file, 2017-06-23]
Noisebox-2015-resources/Noisebox-2015-boxes/cuts/noisebox-box7_cut.dxf
16.6 x 15.1 in

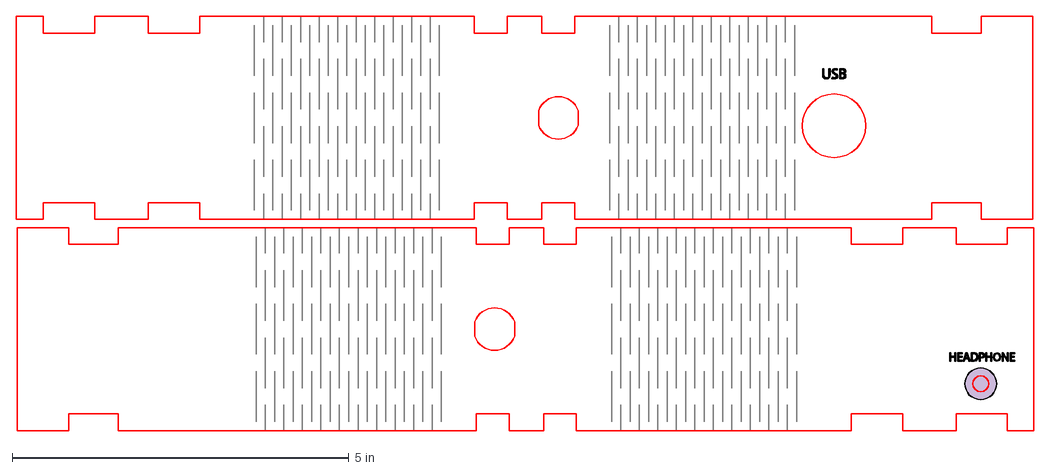
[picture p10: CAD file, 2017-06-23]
Noisebox-2015-resources/Noisebox-2015-boxes/cuts/noisebox-box6_3in-sides.dxf
15.1 x 6.15 in

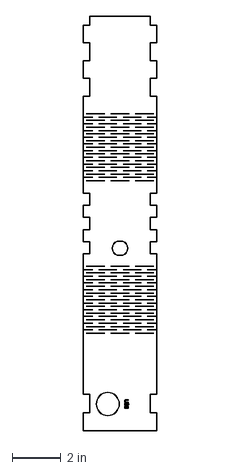
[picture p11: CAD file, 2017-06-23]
Noisebox-2015-resources/Noisebox-2015-boxes/lasercutter-files/noisebox-box3_scrap.dxf
3.00 x 17.0 in

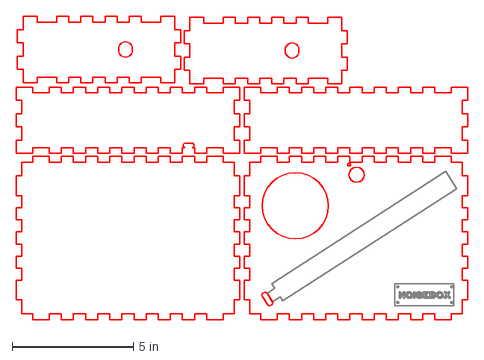
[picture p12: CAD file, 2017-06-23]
Noisebox-2015-resources/Noisebox-2015-boxes/cuts/noisebox1-2.dxf
18.7 x 12.5 in

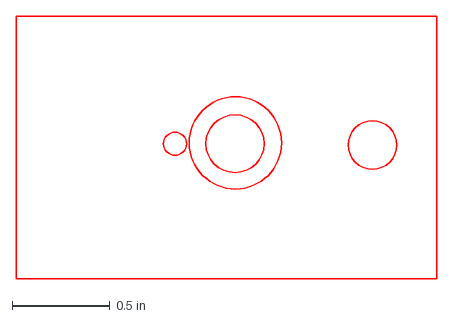
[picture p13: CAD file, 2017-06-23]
Noisebox-2015-resources/Noisebox-2015-boxes/lasercutter-files/laser-cut-text2-in.dxf
2.15 x 1.35 in

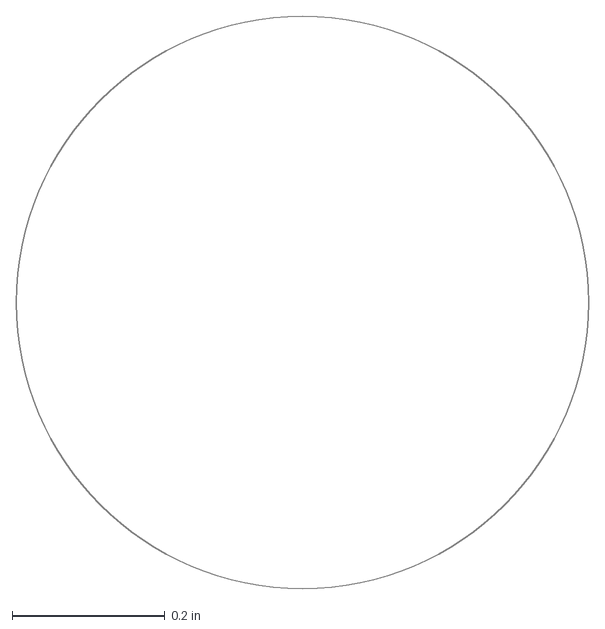
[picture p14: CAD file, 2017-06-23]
Noisebox-2015-resources/Noisebox-2015-boxes/cuts/19mm-circle.dxf
0.748 x 0.748 in

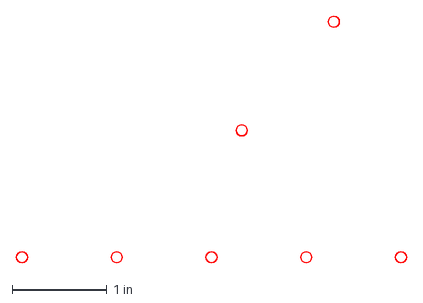
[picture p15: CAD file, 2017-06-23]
Noisebox-2015-resources/Noisebox-2015-boxes/cuts/noisebox-box6_cut-guides.dxf
4.12 x 2.60 in

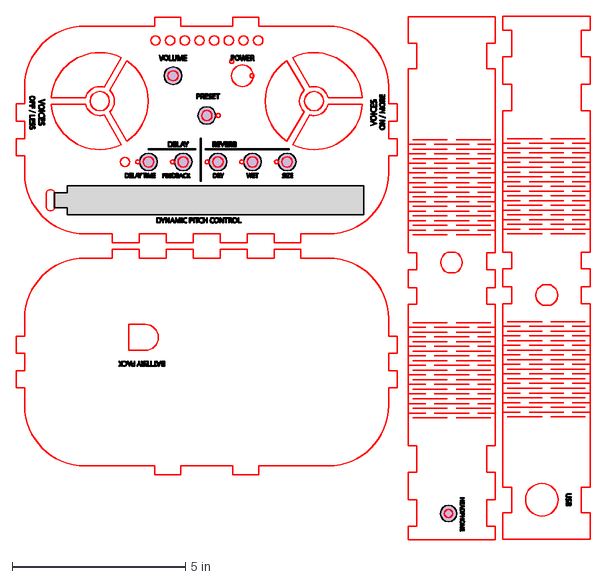
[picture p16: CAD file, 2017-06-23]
Noisebox-2015-resources/Noisebox-2015-boxes/lasercutter-files/noisebox-box6_cut-all.dxf
16.6 x 15.1 in

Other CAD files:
Noisebox-2015-resources/Noisebox-2015-boxes/lasercutter-files/noisebox-box6_cut-guideholes.dxf
Noisebox-2015-resources/Noisebox-2015-boxes/lasercutter-files/laser-cut-text2.dxf
Noisebox-2015-resources/Noisebox-2015-boxes/lasercutter-files/laser-cut-text.dxf
Noisebox-2015-resources/Noisebox-2015-boxes/lasercutter-files/laser-cut-text2-cm.dxf
Noisebox-2015-resources/Noisebox-2015-boxes/lasercutter-files/noisebox-box6_3in-sides.dxf
Noisebox-2015-resources/Noisebox-2015-boxes/lasercutter-files/noisebox-box6_cut-main copy.dxf

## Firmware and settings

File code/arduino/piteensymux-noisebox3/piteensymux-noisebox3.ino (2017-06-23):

#include <math.h>

int r0 = 0;//value of select pin at the 4051 (s0)
int r1 = 0;//value of select pin at the 4051 (s1)
int r2 = 0;//value of select pin at the 4051 (s2)

int led = 13;


int const numAdc = 10; //number of adcs used (number of muxes)
int const numSensor = 8; // number of sensors (on each mux)

int i, j = 0;

//2D array
int adcArray [numAdc][numSensor];
int adcArrayTemp [numAdc][numSensor];

//Single vector array with one byte per sensor
byte adcArrayByte [numAdc][numSensor];

void setup() {

  //led pin output mode
  pinMode(led, OUTPUT);

  for (int i = 0; i < 3; i++) {
    digitalWrite(led, HIGH);
    delay(200);
    digitalWrite(led, LOW);
    delay(800);
  }

  //Initialize serial coms
  //Serial.begin(57600); //Arduino debug serial
  Serial2.begin(57600, SERIAL_8N1);//Pi serial
  //Serial3.begin(31250); //MIDI serial

  for (int i = 0; i < 10; i++) {
    digitalWrite(led, HIGH);
    delay(100);
    digitalWrite(led, LOW);
    delay(100);
  }

  //mux control pins initialization
  pinMode(2, OUTPUT);// s0
  pinMode(3, OUTPUT);// s1
  pinMode(4, OUTPUT);// s2

  //turn led on
  digitalWrite(led, HIGH);   // turn the LED on (HIGH is the voltage level)
}

//define MIDI output function for control change messages
void sendMidicc (int channel, int cc, float value) {
  Serial3.write(char(175 + channel));
  Serial3.write(char(cc));
  Serial3.write(char(value));
};

/////////////////MAIN LOOP/////////////////
void loop() {

  for (i = 0; i < numSensor; i++) {

    // bit counter
    r0 = bitRead(i, 0);
    r1 = bitRead(i, 1);
    r2 = bitRead(i, 2);

    // write bit counter pins
    digitalWrite(2, r0);
    digitalWrite(3, r1);
    digitalWrite(4, r2);

    //delay(1);

    for (j = 0; j < numAdc; j++) {

      //read analog values into array
      adcArrayTemp[j][i] = analogRead(j);

      adcArrayByte[j][i] = (byte)(round((float)analogRead(j) / 1024 * 250)); //reserve slip encoding bytes

      //filter  noise (if difference between stored and temp values is bigger than...)
      if ( (adcArrayTemp[j][i] - adcArray[j][i]) > 5 || (adcArray[j][i] - adcArrayTemp[j][i]) > 5 ) {

        adcArray[j][i] = adcArrayTemp[j][i];

        byte mux = j;
        byte sensor = i;
        // byte mask1 = 240;
        // byte mask2 = 15;

//        //debug
//        if (mux == 3 ) {
//          Serial.print(mux);
//          Serial.print(" ");
//          Serial.print("/");
//          Serial.print(sensor);
//          Serial.print("/");
//          if (i == 0) {
//            Serial.print(adcArrayByte[j][i]); 
//          }
//        }

        mux = mux << 4;

        byte id = mux | sensor;

        //send to beaglebone with 8 bit precision
        Serial2.write(253);
        Serial2.write(254);
        // Serial2.write(j);
        // Serial2.write(i);
        Serial2.write(id);
        Serial2.write(adcArrayByte[j][i]);
        Serial2.write(255);

        delay(1);

        //send midi
        // sendMidicc(1, 60 +i, float(adcArray[0][i])/1024 *127);
      };
    };
  }
}

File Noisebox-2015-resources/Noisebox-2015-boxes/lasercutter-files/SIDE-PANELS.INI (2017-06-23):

[Technics_Laser_Data]
ModifyTechCFG=0
LayersNumber=3
ExportRows=1
ExportColumns=1
ExportRowSpace=0.00000
ExportColumnSpace=0.00000
ExportRowCW=0.00000
ExportColumnCW=0.00000
LogicOrgPositionX=767.97610
LogicOrgPositionY=526.52450
LogicOrgPositionZ=-9999999.00000
AtOnceExport=0
IsTwoLaserWorking=1
TableZeroPositionX=0.00000
TableZeroPositionY=0.00000
OutputTimes=1
DelayTime=0
FeedLength=0.00000
FeedSpeed=5.00000
FeedDelayTime=0
MinX=634.68242
MaxX=767.97610
MinY=142.75861
MaxY=526.52450
ChangeSerialNo=0
ArrayMinX=634.68242
ArrayMaxX=767.97610
ArrayMinY=142.75861
ArrayMaxY=526.52450
LayerColor_0=8388736
LayerColor_1=0
LayerColor_2=12615935
ClipBoxPower=50.00000
ClipBoxPower2=40.00000
ClipBoxOffsetLen=2.00000
ClipBoxSpeed=400.00000
AlignMachineZPos=0.00000
RouteLength=0.00000
RoutePointNumber=0
OffsetLaserPower=0.00000
OffsetWorkSpeedPer=1.00000
ZHeightForLaserFocus=0.00000
OneWorkNeedTimes=3
TotalWorkTimes=0
[CoordSystem_0]
LogicOrgPosition1=767.97610
LogicOrgPosition2=526.52450
LogicOrgPosition3=-9999999.00000
SPLITBLOCK_NUMBER=2
SPLITBLOCK_NUMBER_0=0.00000
SPLITBLOCK_NUMBER_1=100000.00000
[CreateTechnicsCodeMgr]
PrjHasModifyCFG=0
[TechnicsLayers_0]
TechnicsMode=TECHNICS_LASERENGRAVE
LaserEngravePower=45.00000
LaserEngravePower2=80.00000
LaserEngraveFrequency=20000
LaserEngraveSpeed=450.00000
LaserEngraveBlowGasType=1
LaserEngraveFillCircleR=2.50000
LaserEngraveFillCircleSpace=2.50000
LaserEngraveFillCircle=0
LaserEngraveFillCircleType=0
LaserEngraveTwoDirector=1
LaserEngraveScanDirector=0
LaserEngraveScanStepLen=0.06000
LaserEngraveExpandPenWidth=0
LaserEngraveExpandPenWidthScale=30.00000
LaserCutConnerPower=17.00000
LaserCutWorkPower=100.00000
LaserCutConnerPower2=30.00000
LaserCutWorkPower2=50.00000
LaserCutFrequency=5000
LaserCutOptimizePathType=0
LaserCutInnerToOuter=1
LaserCutInnerToOuter2=0
LaserCutDownToUpper=0
LaserCutBlockHeight=150.00000
LaserCutAutoSetPathDir=1
LaserCutCicleMinSegNumber=36
LaserCutDisperseLength=0.02000
LaserCutCloseGapLength=0.00000
LaserCutOverlapLength=0.00000
LaserCutAdjustForClose=1
LaserCutQXEnterLength=0.00000
LaserCutDelayMoveTime=0.00000
LaserCutOpenGZDelayTime=0.00000
LaserCutOpenLaserDelayTime=0.00000
LaserCutCloseLaserDelayTime=0.00000
LaserCutDelayTimeAfterCloseLaser=0.00000
LaserCutOneAxisBackLashLength=0.00000
LaserCutTwoAxisBackLashLength=0.00000
LaserCutBackLashAddSpaceLength=8.00000
LaserCutBlowGasType=2
LaserCutAheadBlowGasTimes=0.00000
LaserCutNoCloseGasTimes=0.00000
LaserCutSpeed=7.00000
LaserCutGWAcc=3000.00000
LaserCutGWTime=0.01000
LaserCutTrackSize=100
LaserCutLineLength=0.00000
SpaceCutLineLength=0.00000
bSpaceLineFirst=0
LaserCutAdjustMove=0
LaserCutAdjustMoveDelay=0.00000
LaserCutUpLen=0.00000
LaserCutCircleSpeedNum=0
GROUP_ROWS_0=1
GROUP_COLUMNS_0=1
GROUP_ROWSPACE_0=0.00000
GROUP_COLUMNSPACE_0=0.00000
GROUP_ROWCWSPACE_0=0.00000
GROUP_COLUMNCWSPACE_0=0.00000
GROUP_MINX_0=672.81905
GROUP_MAXX_0=752.49435
GROUP_MINY_0=149.20438
GROUP_MAXY_0=210.70378
[TechnicsLayers_12615935]
TechnicsMode=TECHNICS_LASERCUT
LaserEngravePower=45.00000
LaserEngravePower2=80.00000
LaserEngraveFrequency=20000
LaserEngraveSpeed=450.00000
LaserEngraveBlowGasType=1
LaserEngraveFillCircleR=2.50000
LaserEngraveFillCircleSpace=2.50000
LaserEngraveFillCircle=0
LaserEngraveFillCircleType=0
LaserEngraveTwoDirector=1
LaserEngraveScanDirector=0
LaserEngraveScanStepLen=0.06000
LaserEngraveExpandPenWidth=0
LaserEngraveExpandPenWidthScale=30.00000
GROUP_ROWS_0=1
GROUP_COLUMNS_0=1
GROUP_ROWSPACE_0=0.00000
GROUP_COLUMNSPACE_0=0.00000
GROUP_ROWCWSPACE_0=0.00000
GROUP_COLUMNCWSPACE_0=0.00000
GROUP_MINX_0=634.68242
GROUP_MAXX_0=767.97610
GROUP_MINY_0=142.75861
GROUP_MAXY_0=526.52450
LaserCutConnerPower=17.00000
LaserCutWorkPower=100.00000
LaserCutConnerPower2=30.00000
LaserCutWorkPower2=50.00000
LaserCutFrequency=5000
LaserCutOptimizePathType=0
LaserCutInnerToOuter=1
LaserCutInnerToOuter2=0
LaserCutDownToUpper=0
LaserCutBlockHeight=150.00000
LaserCutAutoSetPathDir=1
LaserCutCicleMinSegNumber=36
LaserCutDisperseLength=0.02000
LaserCutCloseGapLength=0.00000
LaserCutOverlapLength=0.00000
LaserCutAdjustForClose=1
LaserCutQXEnterLength=0.00000
LaserCutDelayMoveTime=0.00000
LaserCutOpenGZDelayTime=0.00000
LaserCutOpenLaserDelayTime=0.00000
LaserCutCloseLaserDelayTime=0.00000
LaserCutDelayTimeAfterCloseLaser=0.00000
LaserCutOneAxisBackLashLength=0.00000
LaserCutTwoAxisBackLashLength=0.00000
LaserCutBackLashAddSpaceLength=8.00000
LaserCutBlowGasType=2
LaserCutAheadBlowGasTimes=0.00000
LaserCutNoCloseGasTimes=0.00000
LaserCutSpeed=7.00000
LaserCutGWAcc=3000.00000
LaserCutGWTime=0.01000
LaserCutTrackSize=100
LaserCutLineLength=0.00000
SpaceCutLineLength=0.00000
bSpaceLineFirst=0
LaserCutAdjustMove=0
LaserCutAdjustMoveDelay=0.00000
LaserCutUpLen=0.00000
LaserCutCircleSpeedNum=0
[TechnicsLayers_8388736]
TechnicsMode=TECHNICS_LASERENGRAVE
LaserEngravePower=100.00000
LaserEngravePower2=80.00000
LaserEngraveFrequency=20000
LaserEngraveSpeed=90.00000
LaserEngraveBlowGasType=1
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
